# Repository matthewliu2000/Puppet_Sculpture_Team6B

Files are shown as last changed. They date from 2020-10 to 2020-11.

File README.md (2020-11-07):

# Puppet_Sculpture_Team6B
github repository for Team 6B ECE3872 Sculpture Project

# Hardware
1. PCB Schematic (shield_schematic.sh)
2. shield_schematic.brd
3. PCB Eagle Files: ECE3872A_6B_PCB_Shield.zip

# Software
1. HW & SW Component Level Tests: in test_code Folder
2. Draft Simulation Code: ArduinoSimulationCode.ino
3. Final Simulation Code: ArduinoSimulationCodeV2.ino

# Final Demonstration: 
https://youtu.be/2q0zukCzHsM

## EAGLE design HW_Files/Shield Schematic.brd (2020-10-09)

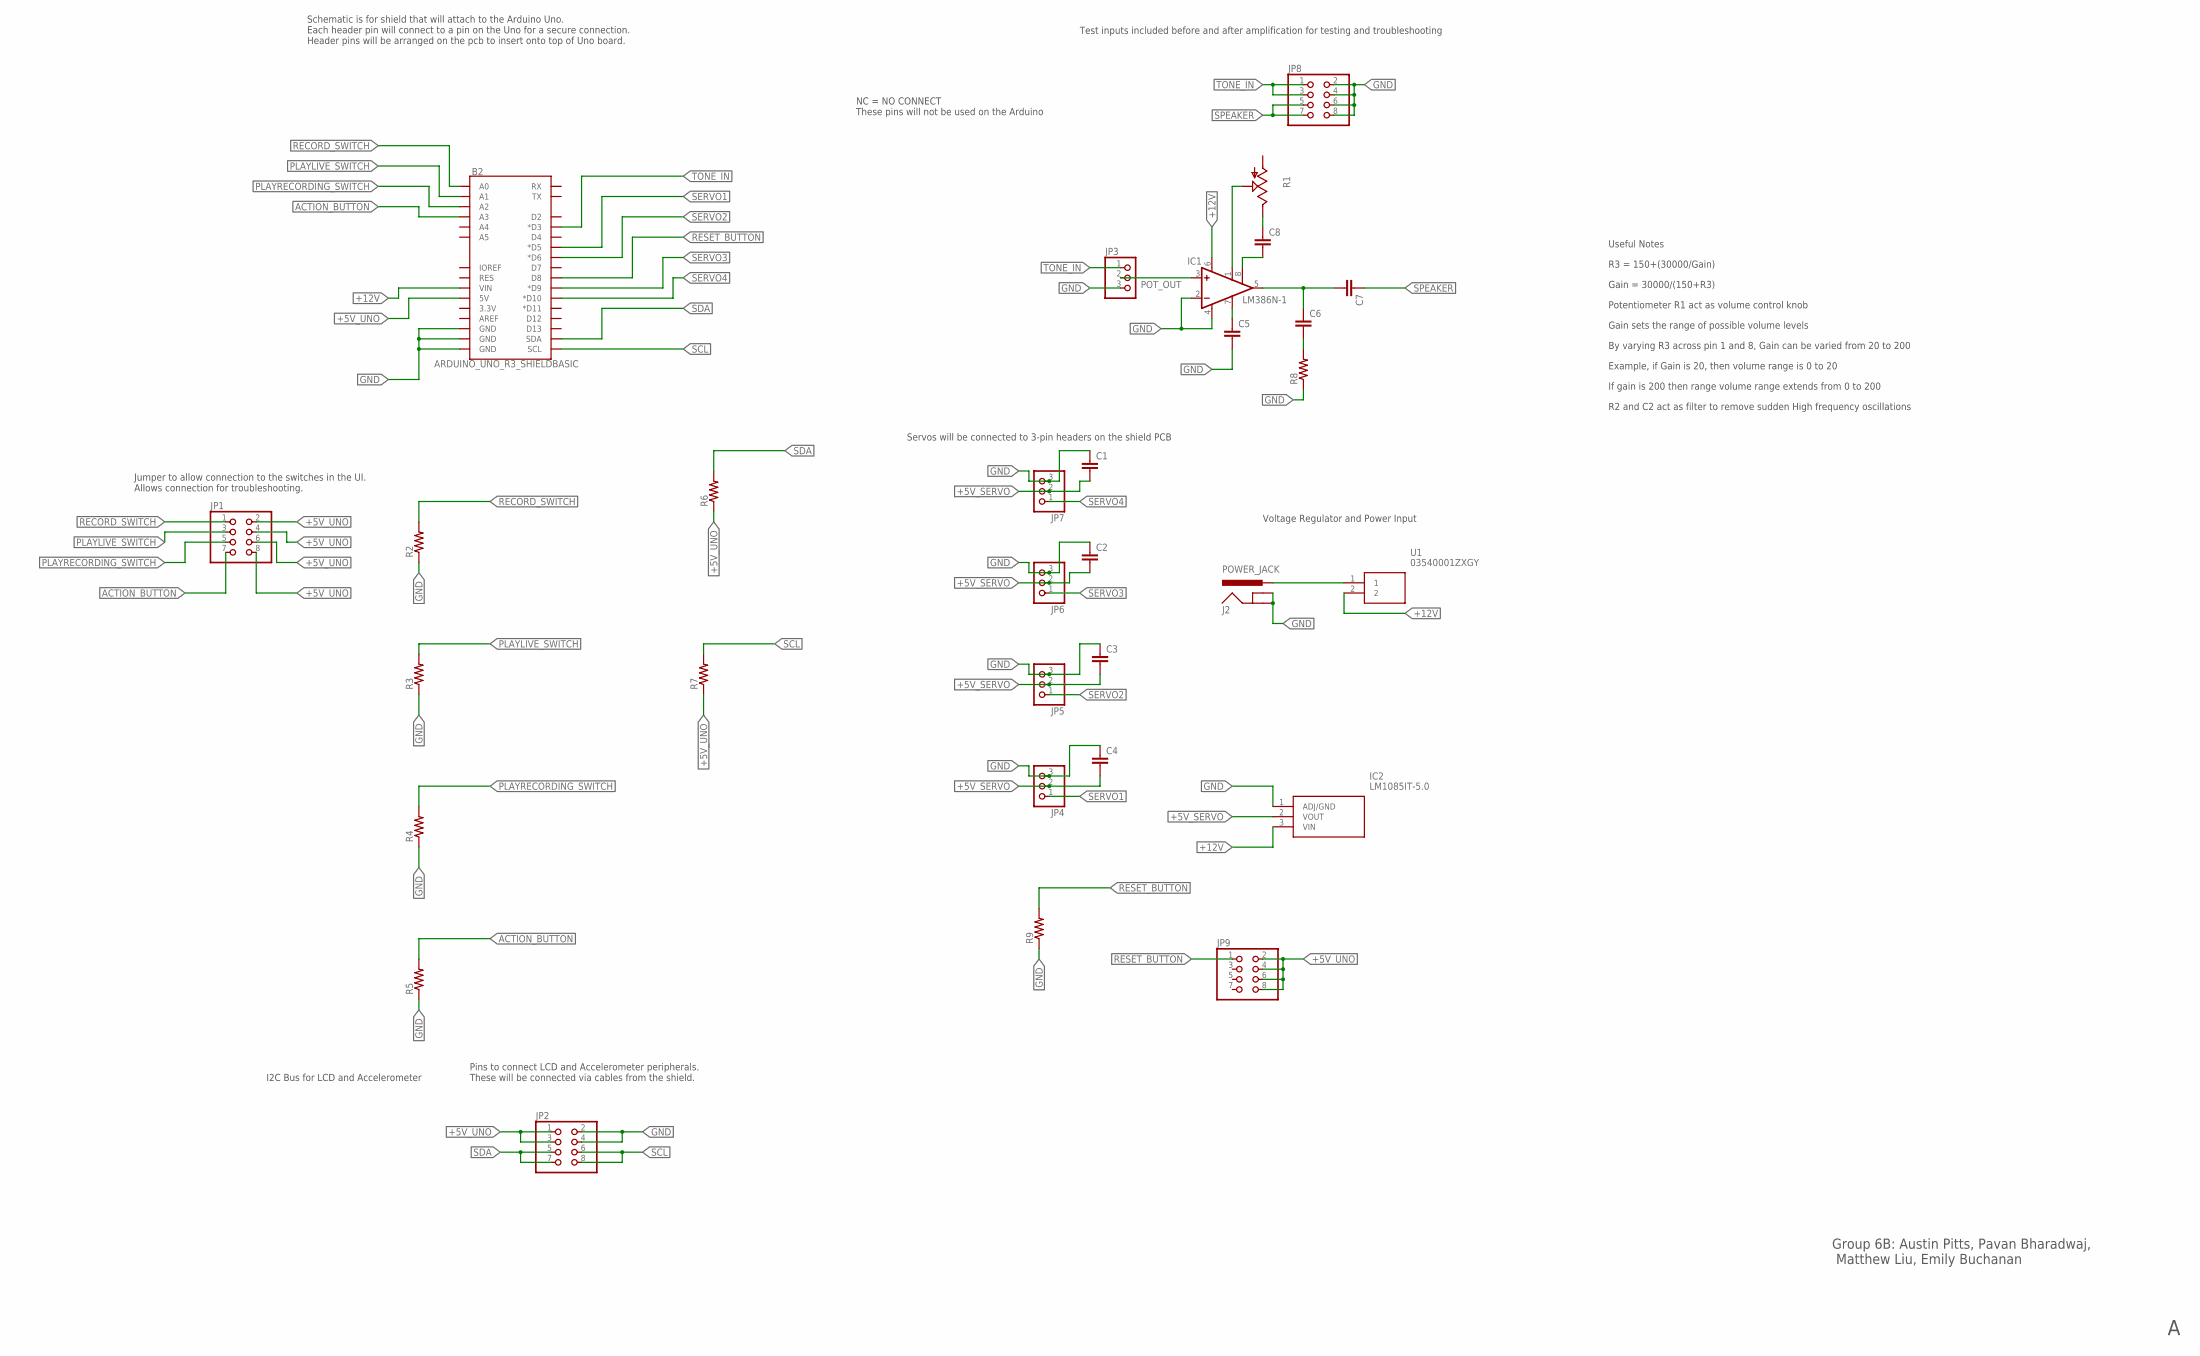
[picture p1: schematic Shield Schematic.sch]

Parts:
B2: ARDUINO_UNO_R3_SHIELDBASIC; UNO_R3_SHIELD
C1, C2, C3, C4, C5, C6, C7, C8: C2,5-3; C2.5-3
IC1: LM386N-1; DIL08
IC2: LM1085IT-5.0; TO254P470X1016X2222-3P
J2: POWER_JACK; POWER_JACK_PTH
JP1, JP2, JP8, JP9: PINHD-2X4; 2X04
JP3, JP4, JP5, JP6, JP7: PINHD-1X3; 1X03
R1: TRIM_US-B25P; B25P
R2, R3, R4, R5, R6, R7, R8, R9: R-US_0207/7; 0207/7
U1: 03540001ZXGY; 03540101ZXGY

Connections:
+5V_SERVO: C1.2, C2.2, C3.2, C4.2, IC2.2 (VOUT), JP4.2, JP5.2, JP6.2, JP7.2
+5V_UNO: B2.5V, JP1.2, JP1.4, JP1.6, JP1.8, JP2.1, JP2.3, JP9.2, JP9.4, JP9.6, JP9.8, R6.1, R7.1
+12V: B2.VIN, IC1.6 (VS), IC2.3 (VIN), U1.2
ACTION_BUTTON: B2.A3, JP1.7, R5.2
GND: B2.GND@0 (GND), B2.GND@1 (GND), B2.GND@2 (GND), C1.1, C2.1, C3.1, C4.1, C5.2, IC1.2 (-IN), IC1.4 (GND), IC2.1 (ADJ/GND), J2.GND, J2.GNDBREAK, JP2.2, JP2.4, JP3.3, JP4.3, JP5.3, JP6.3, JP7.3, JP8.2, JP8.4, JP8.6, JP8.8, R2.1, R3.1, R4.1, R5.1, R8.1, R9.1
unnamed: J2.PWR, U1.1
unnamed: C6.1, C7.2, IC1.5 (OUT)
unnamed: C6.2, R8.2
unnamed: C5.1, IC1.7 (BYPASS)
unnamed: C8.2, IC1.8 (GAIN)
unnamed: C8.1, R1.E
unnamed: IC1.1 (GAIN), R1.S
PLAYLIVE_SWITCH: B2.A1, JP1.3, R3.2
PLAYRECORDING_SWITCH: B2.A2, JP1.5, R4.2
POT_OUT: IC1.3 (+IN), JP3.2
RECORD_SWITCH: B2.A0, JP1.1, R2.2
RESET_BUTTON: B2.D8, JP9.1, R9.2
SCL: B2.SCL, JP2.6, JP2.8, R7.2
SDA: B2.SDA, JP2.5, JP2.7, R6.2
SERVO1: B2.D5 (*D5), JP4.1
SERVO2: B2.D6 (*D6), JP5.1
SERVO3: B2.D9 (*D9), JP6.1
SERVO4: B2.D10 (*D10), JP7.1
SPEAKER: C7.1, JP8.5, JP8.7
TONE_IN: B2.D3 (*D3), JP3.1, JP8.1, JP8.3

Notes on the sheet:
Potentiometer R1 act as volume control knob
R2 and C2 act as filter to remove sudden High frequency oscillations
Gain sets the range of possible volume levels
Gain = 30000/(150+R3)
R3 = 150+(30000/Gain)
Useful Notes
By varying R3 across pin 1 and 8, Gain can be varied from 20 to 200
Example, if Gain is 20, then volume range is 0 to 20
If gain is 200 then range volume range extends from 0 to 200
I2C Bus for LCD and Accelerometer
Schematic is for shield that will attach to the Arduino Uno. Each header pin will connect to a pin on the Uno for a secure connection. Header pins will be arranged on the pcb to insert onto top of Uno board.
Servos will be connected to 3-pin headers on the shield PCB
Pins to connect LCD and Accelerometer peripherals. These will be connected via cables from the shield.
NC = NO CONNECT These pins will not be used on the Arduino
Voltage Regulator and Power Input
Test inputs included before and after amplification for testing and troubleshooting
Group 6B: Austin Pitts, Pavan Bharadwaj, Matthew Liu, Emily Buchanan
Jumper to allow connection to the switches in the UI. Allows connection for troubleshooting.

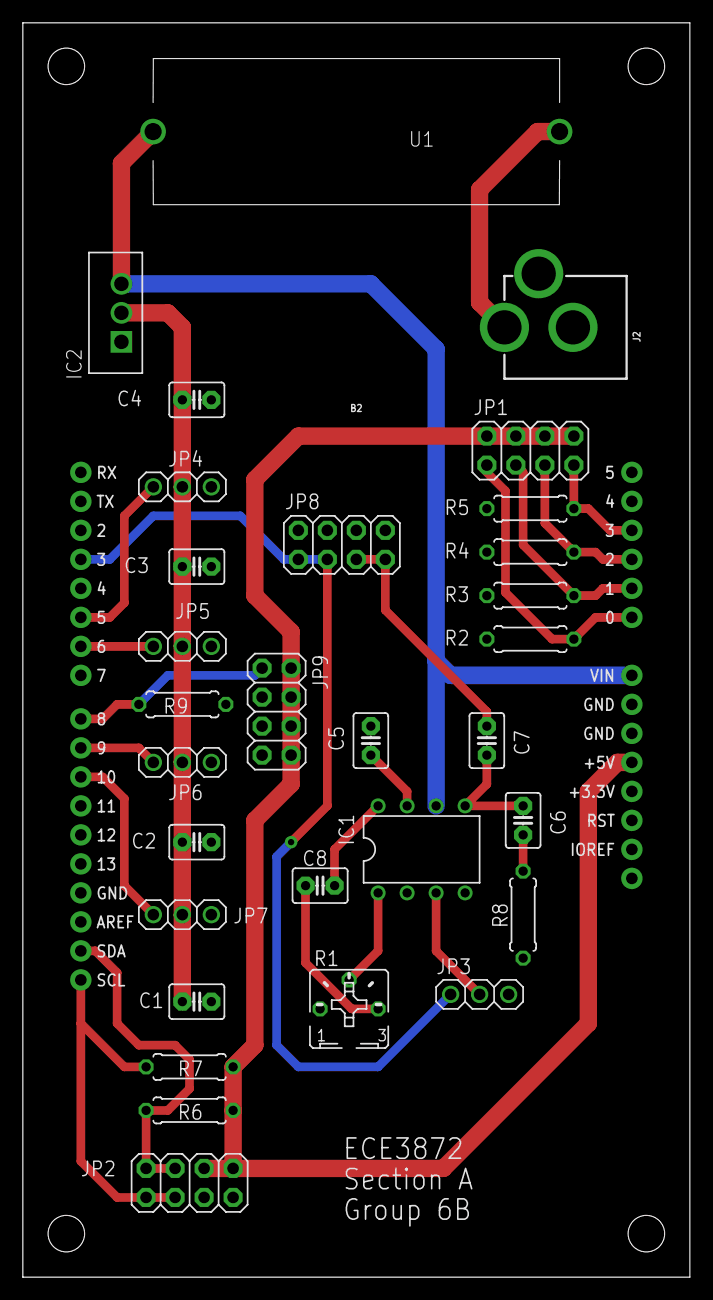
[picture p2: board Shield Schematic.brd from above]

Board: 2 copper layers, 58.4 x 109.9 mm, 31 parts (0 on the bottom side), 25 nets.

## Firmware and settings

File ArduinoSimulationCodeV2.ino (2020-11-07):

/*
ECE3872 Project Software Assignment
Group 6B: Austin Pitts, Emily Buchanan, Matthew Liu, Pavan Bharadwaj
Fall 2020 Semester


*/

#include <Servo.h>
#include <Wire.h>
#include <Adafruit_MSA301.h>
#include <Adafruit_Sensor.h>
//Declare Accelerometer Object
Adafruit_MSA301 msa;
//Declare servo objects
Servo servo1;
Servo servo2;
Servo servo3;
Servo servo4;


//Switch Variables
bool isRecord = false;
bool isPlayLive = false;
bool isPlayRecording = false;
//Permission Variables
bool canRecord = false;
bool canPlayRecording = false;
bool canPlayLive = false;

//Pin Number Assignments
const int speakerPin = 3;
const int recordSwitch = 16;
//const int playLiveSwitch = 17;
const int playRecordingSwitch = 17;
const int actionButton = 15;
const int resetButton = 14;
const int servo1Pin = 5;
const int servo2Pin = 6;
const int servo3Pin = 9;
const int servo4Pin = 10;
//Keypad Pin Assignments
const int pinA = 8;
const int pinB = 2;
const int pinC = 4;
const int pinD = 19;
const int pin1 = 11;
const int pin2 = 12;
const int pin3 = 13;
//Note Frequencies
const unsigned int A = 110;
const unsigned int B2 = 123;
const unsigned int C3 = 131;
const unsigned int D3 = 147;
const unsigned int E3 = 165;
const unsigned int F3 = 175;
const unsigned int G3 = 196;
const unsigned int Gsharp3 = 208;

//Keypad Matrix
const int rowPins[]={pinA,pinB,pinC};
const int columnPins[]={pin1,pin2,pin3};
const int keyPadNotes[3][3]= {{A,B2,C3},{D3,E3,F3},{G3,Gsharp3,A}};
int keyPadInput[3][3]={{0,0,0},{0,0,0},{0,0,0}};



//Prerecorded Note Array
int RecordingLength = 40;
int Recording[] = {A,B2,C3,D3,E3,F3,G3,Gsharp3,G3,F3,E3,D3,C3,B2,A,B2,C3,D3,E3,F3,G3,Gsharp3,G3,F3,E3,D3,C3,B2,A,B2,C3,D3,E3,F3,G3,Gsharp3,G3,F3,E3,D3};
//Unique Servo positions for different notes in order from A-Gsharp3
int servo1Pos[] = {45,90,-45,-90,45,90,-45,-90};
int servo2Pos[] = {90,-45,-90,45,-90,45,90,-45};
int servo3Pos[] = {-45,-90,45,90,90,-45,-90,45};
int servo4Pos[] = {-90,45,90,-45,-45,-90,45,90};

//Array that the notes input is stored in.  Initialized to all zeros in setup.
int inputRecording[40];

//Function that reads keypad input and returns note
int readKeypad(){

  for(int i = 0;i<3;i++){
    for(int j=0;j<3;j++){
      keyPadInput[i][j] = 0;
      }
    }

int rowInput=0;
int colInput=0;

  for(int i = 0;i<3;i++){
    digitalWrite(rowPins[i],HIGH);
    for(int j=0;j<3;j++){
       keyPadInput[i][j] = digitalRead(columnPins[j]);
    }
    digitalWrite(rowPins[i],LOW);
  }

  for(int row = 0;row<3;row++){
    for(int col = 0;col<3;col++){
      if(keyPadInput[row][col] == 1){
        rowInput = row;
        colInput = col;
        break;
        }
      else{}
      
      }
    }

  return keyPadNotes[rowInput][colInput];
    
  }

int readAccel(){

  sensors_event_t event; 
  msa.getEvent(&event);

  double Zaccel = event.acceleration.z;
  Serial.println(Zaccel);
  double Xaccel = event.acceleration.x;

  if(Zaccel > 0 && Zaccel < 2.45 && Xaccel < 0){
    return A;
    }
  else if (Zaccel > 2.45 && Zaccel < 4.9 && Xaccel < 0){
    return B2;
    }
  else if (Zaccel >4.9 && Zaccel < 7.35 && Xaccel < 0){
    return C3;
    }
  else if (Zaccel > 7.35 && Zaccel < 9.8 && Xaccel < 0){
    return D3;
    }
  else if (Zaccel > 0 && Zaccel < 2.45 && Xaccel > 0){
    return E3;
    }
  else if (Zaccel > 2.45 && Zaccel < 4.9 && Xaccel > 0){
    return F3;
    }
  else if (Zaccel > 4.9 && Zaccel < 7.35 && Xaccel > 0){
    return G3;
    }
  else if (Zaccel > 7.35 && Zaccel < 9.8 && Xaccel > 0){
    return Gsharp3;
    }
  else {
    return A;
    }

    
  }
  

  
//Takes a note as input and sets servos to unique positions based on the note
void driveServos(int note){
  switch(note){
    case A:
    servo1.write(servo1Pos[0]);
    servo2.write(servo2Pos[0]);
    servo3.write(servo3Pos[0]);
    servo4.write(servo4Pos[0]);
    break;
    case B2:
    servo1.write(servo1Pos[1]);
    servo2.write(servo2Pos[1]);
    servo3.write(servo3Pos[1]);
    servo4.write(servo4Pos[1]);
    break;
    case C3:
    servo1.write(servo1Pos[2]);
    servo2.write(servo2Pos[2]);
    servo3.write(servo3Pos[2]);
    servo4.write(servo4Pos[2]);
    break;
    case D3:
    servo1.write(servo1Pos[3]);
    servo2.write(servo2Pos[3]);
    servo3.write(servo3Pos[3]);
    servo4.write(servo4Pos[3]);
    break;
    case E3:
    servo1.write(servo1Pos[4]);
    servo2.write(servo2Pos[4]);
    servo3.write(servo3Pos[4]);
    servo4.write(servo4Pos[4]);
    break;
    case F3:
    servo1.write(servo1Pos[5]);
    servo2.write(servo2Pos[5]);
    servo3.write(servo3Pos[5]);
    servo4.write(servo4Pos[5]);
    break;
    case G3:
    servo1.write(servo1Pos[6]);
    servo2.write(servo2Pos[6]);
    servo3.write(servo3Pos[6]);
    servo4.write(servo4Pos[6]);
    break;
    case Gsharp3:
    servo1.write(servo1Pos[7]);
    servo2.write(servo2Pos[7]);
    servo3.write(servo3Pos[7]);
    servo4.write(servo4Pos[7]);
    break;
    }
  }

//Takes an array pointer as input and instructs the arduino to play the notes and call driveServos() to set motor positions
void playRecordedNotes(int *sequence,int Length){

  for(int i = 0; i<(Length); i++){
    checkInputs();
    if(!isPlayRecording){
      break;
      }
    if (checkButton(resetButton)) {
      resetPermissions();
      break;}
    else{
      if(sequence[i] != 0){
       driveServos(sequence[i]);
      tone(speakerPin,sequence[i]);
      //driveServos(sequence[i]);
      delay(500);
      noTone(speakerPin);
      //delay(500);
      //noTone(speakerPin);
      delay(50);}
      else if(sequence[i] == 0){
        break;
        }
        }
      }
    }

//Function that updates the current state of rotary switch
void checkInputs() {
  isPlayLive = !(digitalRead(playRecordingSwitch) || digitalRead(recordSwitch)) ;
  isRecord = digitalRead(recordSwitch);
  isPlayRecording = digitalRead(playRecordingSwitch);
}

/*
  Resets permission variables in order to only allow transitions to states that are available from the idle state.

*/
void resetPermissions() {
  canRecord = false;
  canPlayRecording = false;
  canPlayLive = false;
}

//returns boolean value to indicate whether a button has been pressed.
bool checkButton(int button) {
  return digitalRead(button);
}

/*
 * Idle state that indicates the rotary switch is set to Record mode
 * State machine can only transition to Record mode once it has passed through readyToRecord
 * and canRecord has been set to true
 */
void readyToRecord() {
  while (isRecord) {
    digitalWrite(7,HIGH);
    Serial.println("ReadyToRecord");
    checkInputs();
    resetPermissions();
    canRecord = true;
    if (checkButton(actionButton)) {
      break;
    }
    if (checkButton(resetButton)) {
      resetPermissions();
      break;
    }
  }
  digitalWrite(7,LOW);
  
}

/*
 * Idle state that indicates the rotary switch is set to Play Recording mode
 * State machine must pass through this state before it can play the recording
*/
void readyToPlayRecording() {
  while (isPlayRecording) {
    Serial.println("ReadyToPlayRecording");
    checkInputs();
    resetPermissions();
    canPlayRecording = true;
    if (checkButton(actionButton)) {
      break;
    }
    if (checkButton(resetButton)) {
      resetPermissions();
      break;
    }
  }
}

/*
 * Idle state that indicates the rotary switch is set to the Play Live mode
 * State machine must pass through this state before it can play Live
 */

void readyToPlayLive() {
  while (isPlayLive) {
    Serial.println("ReadyToPlayLive");
    checkInputs();
    resetPermissions();
    canPlayLive = true;
    if (checkButton(actionButton)) {
      break;
    }
    if (checkButton(resetButton)) {
      resetPermissions();
      break;
    }
  }
}

/*
 * State that executes the necessary functions to play a recorded sequence of notes
 */

void playRecording() {

  while (canPlayRecording && isPlayRecording) {
    
    Serial.println("PlayRecording");
    checkInputs();
    playRecordedNotes(inputRecording,RecordingLength);
    if (checkButton(resetButton)) {
      resetPermissions();
      break;
    }
  }
}
/*
 * State that plays notes in real time in response to user input
 */
void playLive() {
  while (canPlayLive && isPlayLive) {
    Serial.println("PlayLive");
    checkInputs();
    if (checkButton(resetButton)) {
      resetPermissions();
      break;
    }
    int note = readAccel();
    Serial.println(note);
    tone(speakerPin,note);
    driveServos(note);
    delay(50);
    noTone(speakerPin);
    delay(10);
  }
}

/*
 * State that records user input and stores the sequence of notes in memory
 */

void record() {
  while (canRecord && isRecord) {
    Serial.println("Record");
    int startingIndex = 0;
    bool isFull = false;
    checkInputs();
    if (checkButton(resetButton)) {
      resetPermissions();
      break;}

    for(int i=0;i<RecordingLength;i++){
      if(inputRecording[i] == 0){
        startingIndex = i;
        isFull = false;
        break;
        }
        isFull = true;
      }
      if(isFull){
        readyToRecord();
        }
      

    if(!isFull){
      for(int i=startingIndex; i<RecordingLength;i++){
        checkInputs();
        if (checkButton(resetButton)) {
          resetPermissions();
          break;
          }
        int note = readAccel();
        inputRecording[i] = note;
        tone(speakerPin,note);
        delay(500);
        noTone(speakerPin);
        delay(10);
        startingIndex = i;
      }
    }
  }
}

//State that checks for a 3 second reset button press and deletes recording
void EraseLoop(){
  int counter = 0;
  while(checkButton(resetButton)){
    delay(500);
    counter++;
    if(counter == 6){
      for (int i =0;i<RecordingLength;i++){
        inputRecording[i] = 0;
        }
        break;
      }
    
    }
  
  }

//Setup runs once and sets proper pin modes
void setup() {
  //Input Switches and buttons
  for (int i = 14; i <= 18; i++) {
    pinMode(i, INPUT);
  }
  //Begin Serial Communications
  Serial.begin(115200);

  Serial.println("Adafruit MSA301 test!");
  
  // Try to initialize!
  if (! msa.begin()) {
    Serial.println("Failed to find MSA301 chip");
    while (1) { delay(10); }
  }
  Serial.println("MSA301 Found!");

  //msa.setDataRate(MSA301_DATARATE_31_25_HZ);
  Serial.print("Data rate set to: ");
  switch (msa.getDataRate()) {
    case MSA301_DATARATE_1_HZ: Serial.println("1 Hz"); break;
    case MSA301_DATARATE_1_95_HZ: Serial.println("1.95 Hz"); break;
    case MSA301_DATARATE_3_9_HZ: Serial.println("3.9 Hz"); break;
    case MSA301_DATARATE_7_81_HZ: Serial.println("7.81 Hz"); break;
    case MSA301_DATARATE_15_63_HZ: Serial.println("15.63 Hz"); break;
    case MSA301_DATARATE_31_25_HZ: Serial.println("31.25 Hz"); break;
    case MSA301_DATARATE_62_5_HZ: Serial.println("62.5 Hz"); break;
    case MSA301_DATARATE_125_HZ: Serial.println("125 Hz"); break;
    case MSA301_DATARATE_250_HZ: Serial.println("250 Hz"); break;
    case MSA301_DATARATE_500_HZ: Serial.println("500 Hz"); break;
    case MSA301_DATARATE_1000_HZ: Serial.println("1000 Hz"); break;
  }

  //msa.setPowerMode(MSA301_SUSPENDMODE);
  Serial.print("Power mode set to: ");
  switch (msa.getPowerMode()) {
    case MSA301_NORMALMODE: Serial.println("Normal"); break;
    case MSA301_LOWPOWERMODE: Serial.println("Low Power"); break;
    case MSA301_SUSPENDMODE: Serial.println("Suspend"); break;
  }

  //msa.setBandwidth(MSA301_BANDWIDTH_31_25_HZ);
  Serial.print("Bandwidth set to: ");
  switch (msa.getBandwidth()) {
    case MSA301_BANDWIDTH_1_95_HZ: Serial.println("1.95 Hz"); break;
    case MSA301_BANDWIDTH_3_9_HZ: Serial.println("3.9 Hz"); break;
    case MSA301_BANDWIDTH_7_81_HZ: Serial.println("7.81 Hz"); break;
    case MSA301_BANDWIDTH_15_63_HZ: Serial.println("15.63 Hz"); break;
    case MSA301_BANDWIDTH_31_25_HZ: Serial.println("31.25 Hz"); break;
    case MSA301_BANDWIDTH_62_5_HZ: Serial.println("62.5 Hz"); break;
    case MSA301_BANDWIDTH_125_HZ: Serial.println("125 Hz"); break;
    case MSA301_BANDWIDTH_250_HZ: Serial.println("250 Hz"); break;
    case MSA301_BANDWIDTH_500_HZ: Serial.println("500 Hz"); break;
  }

  //msa.setRange(MSA301_RANGE_2_G);
  Serial.print("Range set to: ");
  switch (msa.getRange()) {
    case MSA301_RANGE_2_G: Serial.println("+-2G"); break;
    case MSA301_RANGE_4_G: Serial.println("+-4G"); break;
    case MSA301_RANGE_8_G: Serial.println("+-8G"); break;
    case MSA301_RANGE_16_G: Serial.println("+-16G"); break;
  }

  //msa.setResolution(MSA301_RESOLUTION_14 );
  Serial.print("Resolution set to: ");
  switch (msa.getResolution()) {
    case MSA301_RESOLUTION_14: Serial.println("14 bits"); break;
    case MSA301_RESOLUTION_12: Serial.println("12 bits"); break;
    case MSA301_RESOLUTION_10: Serial.println("10 bits"); break;
    case MSA301_RESOLUTION_8: Serial.println("8 bits"); break;
  }
  //Speaker and Servo pin modes
  pinMode(speakerPin,OUTPUT);
  pinMode(servo1Pin,OUTPUT);
  pinMode(servo2Pin,OUTPUT);
  pinMode(servo3Pin,OUTPUT);
  pinMode(servo4Pin,OUTPUT);
  //Keypad Pin modes
  pinMode(pinA,OUTPUT);
  pinMode(pinB,OUTPUT);
  pinMode(pinC,OUTPUT);
  pinMode(pinD,OUTPUT);
  pinMode(pin1,INPUT);
  pinMode(pin2,INPUT);
  pinMode(pin3,INPUT);
  pinMode(7,OUTPUT);

  //Initialize Switches
  isRecord = false;
  isPlayLive = false;
  isPlayRecording = false;
  //Initialize Permission Variables
  canRecord = false;
  canPlayRecording = false;
  canPlayLive = false;
  
//Attach Servo Motor Objects to pins
  servo1.attach(servo1Pin);
  servo2.attach(servo2Pin);
  servo3.attach(servo3Pin);
  servo4.attach(servo4Pin);

//Set input recording array to empty (all zeros)
for(int i = 0;i<RecordingLength;i++){
  inputRecording[i] = 0;
  }

}



//Main loop that allows transitions between the states

void loop() {

  checkInputs();
  EraseLoop();
  readyToRecord();
  record();
  readyToPlayRecording();
  playRecording();
  readyToPlayLive();
  playLive();

}






/*// Generated by Proteus Visual Designer for Arduino

  // Peripheral Configuration Code (Do Not Edit)
  //---CONFIG_BEGIN---
  #pragma GCC push_options
  #pragma GCC optimize ("Os")

  #include <core.h> // Required by cpu
  #include <cpu.h>
  #include <TimerOne.h>
  #include <spi.h> // Required by SD1
  #include <WaveStore.h>
  #include <Generic.h>
  #include <WavePlayer.h>

  #pragma GCC pop_options

  // Peripheral Constructors
  CPU &cpu = Cpu;
  TimerOne &timer1 = Timer1;
  GenericSwitch SW1 = GenericSwitch (14);
  GenericButton BTN1 = GenericButton (17);
  GenericSwitch SW2 = GenericSwitch (15);
  GenericSwitch SW3 = GenericSwitch (16);
  GenericButton BTN2 = GenericButton (18);
  WavePlayer &AUDIO1 = WP;
  WaveStore &SD1 = WS;

  void peripheral_setup () {
  AUDIO1.begin (2, 3, 4, 5);
  SD1.begin (10);
  }

  void peripheral_loop() {
  }
  //---CONFIG_END---

  // Flowchart Variables
  bool var_Record;
  bool var_playLive;
  bool var_playRecording;
  bool var_canRecord;
  bool var_canPlayRecording;
  bool var_canPlayLive;
  String var_fileName;

  // Flowchart Routines
  void chart_SETUP() {
  var_Record=false,var_playLive=false,var_playRecording=false,var_canRecord=false,var_canPlayLive=false,var_canPlayRecording=false;

  }

  void chart_LOOP() {
  chart_CheckInputs();
  chart_ReadyToRecord();
  chart_Record();
  chart_ReadyToPlayRecording();
  chart_PlayRecording();
  chart_ReadyToPlayLive();
  chart_PlayLive();
  }

  void chart_ReadyToRecord() {
  while (var_Record) {
  chart_CheckInputs();
  chart_ResetPermissions();
  var_canRecord=true;
  if (!(!BTN1())) goto l10;
  if (!(!BTN2())) goto l9;
  }
  l9:;
  chart_ResetPermissions();
  l10:;
  }

  void chart_CheckInputs() {
  var_Record=SW1(),var_playLive=SW2(),var_playRecording=SW3();
  }

  void chart_ReadyToPlayRecording() {
  while (var_playRecording) {
  chart_CheckInputs();
  chart_ResetPermissions();
  var_canPlayRecording=true;
  if (!(!BTN1())) goto l10;
  if (!(!BTN2())) goto l9;
  }
  l9:;
  chart_ResetPermissions();
  l10:;
  }

  void chart_ResetPermissions() {
  var_canRecord=false,var_canPlayRecording=false,var_canPlayLive=false;
  }

  void chart_ReadyToPlayLive() {
  while (var_playLive) {
  chart_CheckInputs();
  chart_ResetPermissions();
  var_canPlayLive=true;
  if (!(!BTN1())) goto l10;
  if (!(!BTN2())) goto l9;
  }
  l9:;
  chart_ResetPermissions();
  l10:;
  }

  void chart_PlayRecording() {
  while (var_canPlayRecording&&var_playRecording) {
  chart_CheckInputs();
  AUDIO1.play("DO.WAV",true);
  delay(100);
  }
  }

  void chart_Record() {
  while (var_Record&&var_canRecord) {
  chart_CheckInputs();
  }
  }

  void chart_PlayLive() {
  while (var_playLive&&var_canPlayLive) {
  chart_CheckInputs();
  AUDIO1.play("RE.WAV",true);
  delay(100);
  }
  }

  // Entry Points and Interrupt Handlers
  void setup () { peripheral_setup();  chart_SETUP(); }
  void loop () { peripheral_loop();  chart_LOOP(); }*/

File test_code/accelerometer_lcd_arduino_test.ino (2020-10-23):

#include <Wire.h>  // Wire library - used for I2C communication
#include <LiquidCrystal.h>


// #### May Need to Change #s ####
int ADXL345 = 0x53; // The ADXL345 sensor I2C address

float X_out, Y_out, Z_out;  // Outputs

// #### May Need to Change #s ####
LiquidCrystal lcd(7,8,9,10,11,12); // initialize library with the numbers of the interface pins

void setup() {
  Serial.begin(9600); // Initiate serial communication for printing the results on the Serial monitor
  Wire.begin(); // Initiate the Wire library
  // Set ADXL345 in measuring mode
  Wire.beginTransmission(ADXL345); // Start communicating with the device
  Wire.write(0x2D); // Access/ talk to POWER_CTL Register - 0x2D

// #### May Need to Change #s ####
  // Setup LCD's columns and rows
  lcd.begin(16,1);
  lcd.clear();

  // Enable measurement
  Wire.write(8); // (8dec -> 0000 1000 binary) Bit D3 High for measuring enable 
  Wire.endTransmission();
  delay(10);
}

void loop() {
  // === Read acceleromter data === //
  Wire.beginTransmission(ADXL345);
  Wire.write(0x32); // Start with register 0x32 (ACCEL_XOUT_H)
  Wire.endTransmission(false);
  Wire.requestFrom(ADXL345, 6, true); // Read 6 registers total, each axis value is stored in 2 registers
  X_out = ( Wire.read()| Wire.read() << 8); // X-axis value
  X_out = X_out/256; //For a range of +-2g, we need to divide the raw values by 256, according to the datasheet
  Y_out = ( Wire.read()| Wire.read() << 8); // Y-axis value
  Y_out = Y_out/256;
  Z_out = ( Wire.read()| Wire.read() << 8); // Z-axis value
  Z_out = Z_out/256;

  // LCD Prints
  // #### May Need to Change #s before/after testing ####
  lcd.setCursor(0,0);
  lcd.print(X_out);
  lcd.setCursor(6,0);
  lcd.print(Y_out);
  lcd.setCursor(12,0)
  lcd.print(Z_out);

  // Serial Monitor Check Prints
  Serial.print("Xa= ");
  Serial.print(X_out);
  Serial.print("   Ya= ");
  Serial.print(Y_out);
  Serial.print("   Za= ");
  Serial.println(Z_out);

  // #### May Need to Change #s before/after testing ####
  // Prevent LCD from updating too fast and become unreadable
  delay(50)
}

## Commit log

2020-10-04 Initial Shield PCB Schematic (Eagle)
    [Shield Schematic.sch]
2020-10-23 Add files via upload
    Testing interface b/n LCD and accelerometer.
    Description:
    Outputs accelerometer measurement values to LCD and serial monitor
2020-11-07 Rename Shield Schematic.brd to HW_Files/Shield Schematic.brd
    [Shield Schematic.brd]
2020-11-07 Rename Shield Schematic.sch to HW_Files_Shield Schematic.sch
    [HW_Files_Shield Schematic.sch]
2020-11-07 Rename HW_Files_Shield Schematic.sch to HW_Files/Shield Schematic.sch
    [Shield Schematic.sch]

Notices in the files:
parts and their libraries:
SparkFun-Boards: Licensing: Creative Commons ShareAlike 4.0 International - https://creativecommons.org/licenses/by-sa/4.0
